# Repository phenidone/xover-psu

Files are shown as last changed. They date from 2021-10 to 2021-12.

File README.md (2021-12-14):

# Preamp Power Supply

This is a PCB design for an analogue preamplifier power supply

## Inputs

Power can be provided as one of:
* high voltage (240V) AC, relay-switched
* high voltage (240V) AC, unswitched,
* low voltage (20+20V) unregulated DC

An opto-isolated input (5-24V DC) is provided to control the power-switching relay.  Low-power (2A) switched AC loads can be
connected via terminals on the PCB, and high power loads (20A) can be switched using spade terminals on the rear of the 
relay.

If the PCB transformer is omitted, unregulated dual-rail DC can be fed into the linear regulator section.  Additional
filter capacitors may also be inserted at this point.  The unmute circuit will NOT work unless the transformer is present or
low-voltage AC is otherwise supplied to the board.

## Outputs

The circuit provides:
* +/- 12-15VDC, linear regulated
* 12VDC from always-on switchmode brick, for control circuits
* un-muting relay output
* 50Hz opto-isolated pulses for external power-sensing logic
* power-relay output

The power-relay terminals can be used as an output port to drive an external
relay, or can be used as an input port to drive the onboard relay if the
remote/relay driver circuit (U2, Q1, etc) is not populated.

The 12VDC output terminal could be used as an input from an external plugpack
if the HLK10M12 is not present.

### Unmute Logic

The UNMUTE output is designed to switch a 12V muting relay and thereby suppress bad noises that occur during power-up/down
brownout of preamplifier and power-amplifier circuits.

The unmute logic uses a slow turn-on RC timer and a fast turn-off RC timer, both of which are charged from opto-isolated pulses
derived from the mains transformer secondary.  The UNMUTE output (12VDC up to 500mA) is enabled after the slow timer charges, 
which is about 1s after power is applied; for a shorter turn-on delay, reduce the value of R2 and/or C1.

When power is withdrawn, the fast timer discharges in about 50ms, which causes Q2 to discharge the C in the slow timer,
thereby immediately shutting off the UNMUTE output and resetting the startup time.

Each RC timer uses a TL431 to provide a distinct transition point, for fast(ish) turn-on/off transitions.

A secondary AC pulse output is provided as bare optoisolator pins, allowing an external logic circuit to safely monitor the presence of AC
power going into the linear regulator.

### Linear Regulation

The dual-rail DC output is designed to power opamp-based preamplifier circuits and as such, has an output of approx 12-15V
DC depending on resistor selection choices.  The circuit should be good for about 250mA, depending on the transformer regulation.

## Construction

The board is very densely populated, and on both sides.  First assemble all the surface-mount components on the board front,
then install all through-hole components (except screw terminals) on the board rear.

### Errata

The pinouts of some TL431 devices have pins 1 and 2 reversed, i.e. they are mis-marked TL432s.  You can, with a little bending
of their leads, install those upside down and it will work.  The layout assumes the pin order is 1=K, 2=R, 3=A.

### Component Sourcing

The major/expensive items required are:
* TE T9GS1L24-12 power relay
* HiLink 10M12 AC/DC switchmode brick
* Vigortronix VTX-120-5412-415 transformer for 15V operation
    * alternative: VTX-120-5412-412 for 12V operation
    * alternative: Block PT-13/2/12 which has a similar footprint
* Bourns PM3700 common-mode choke
* Rectifier filter caps: Panasonic EEEFK 3300u or similar 18mm square electrolytics
* Other silicon and passives - buy it on eBay from China

An 0805 passive sample book is very handy for filling out most of the circuit; low-noise/precision values are not required.

### Output Voltage

Output voltage is selected by voltage dividers on the LM317 and LM337.  
Choose R18 and R28 to be 240R or 270R, then select values for R20 and R23
so that

> R20 = R18 (VOUT / 1.25 - 1)

If R20 is not a convenient value, make a parallel combination e.g. 5k1 and 6k8
in lieu of 3k to get about 15V.

### Regulator Caps

Regulator output capacitors should preferably be tantalum or aluminium electrolytic.
You can use either C6/C14 (SMD) or C7/C15 (through hole) footprints.  Make 
sure the capacitors are rated for notably more than the output voltage, 
e.g. 25V.

Ceramic caps here will cause regulator instability and oscillation.

### Pi Filter

The rectifier filter is a C-R-C pi-filter with 3300u per side.  Choose the resistors (R31, R26 etc) so that
the net voltage drop across them is as much as you can handle, without:
* bringing the unregulated DC rail so low that ripple breaks through the regulators, or
* the resistors overheating (max 100mW each) at your max design-load current

Larger resistors will provide greater ripple smoothing, at the expense of lower voltage
input to the regulators.  Choice will depend on your selection of transformer voltage, 
output voltage, and max expected load current.  A 15V supply has more room here for 
voltage drop (and therefore smoothing) than a 12V supply does.

Bridge them with 0R if you want a simple capacitor-only rectification filter.  Loading all
eight with 10R is probably OK for a 250mA output and will lose you about 0.65V DC and 160mW per rail.

### AC bits

The MOVs and common-mode choke are probably not critical.  Bridge over the 
choke if you're feeling EMI-antisocial, though this may result in HF conducted
EMI reaching your regulated outputs.

Use 500mA M205 slow blow glass fuses; there is one for each of the switchmode and
linear-regulated parts of the supply.  The switched-AC output is not fused, and should be good for 
about 5A before there are issues with terminal blocks.  For switching high-power amplifiers, use the
spade connectors on the rear of the relay.

### Grounding

There are three separate grounds:
* AGND, the centre of the dual-regulated supply
* DGND, ground for the 12V VDD switchmode/logic/control supply
* EARTH, a chassis safety connection

AGND is connected to EARTH via four opposed diodes in a bridge configuration,
which will keep them to no more than about 1.4V apart, but otherwise uncoupled
with respect to noise.

DGND is connected to EARTH via two opposed diodes and a capacitor.  They may
be up to 0.7V apart, and noise from the DC side of the 10M12 should be 
conducted into EARTH via C18.  These ground-lift circuits should be strong 
enough to trip an ELCB if there is a transformer-isolation fault that brings
mains AC power to the low voltage side.

The Vigortronix transformers have exposed steel cores which must be grounded via
mounting screws through the PCB, which are connected via the PCB to the 
EARTH screw terminal.

### PCB

Use a full-thickness (16.mm) PCB; 1mm boards are too flimsy with all of the heavy power supply components mounted.

## TRL and Regulatory

This design is tested and working in a benign environment at Rev.A.  It has not faced MTBF validation,
environmental (thermal+vibration) or EMI compliance testing.

In terms of electrical safety, this design
* is intended for use in Class I (grounded) equipment:
    * a safety-ground connection is mandatory,
    * it must be installed inside an IEC-60950 grounded case per Class I;
* additionally aims to comply with IEC-60950 "reinforced insulation" creepage+clearance rules,
* uses diode-based ground-lift circuits that may not be legal in all jurisdictions for a Class I device,

The design has not been certified by any regulatory body or independent third party testing agency.  You must 
not sell any product containing this power supply without first obtaining certification.

## License

This hardware design is (C) 2021 William Brodie-Tyrrell and is licensed under the CERN OHL; see cern_ohl_v_1_2.pdf

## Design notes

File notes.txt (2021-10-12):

Trace min 10mil for 0.5A

Creepage/clearance per IEC-60950-1
Functional insulation: 3.2/1.5mm
Basic insulation: 3.2/2mm
Reinforced insul: 6.4/4mm

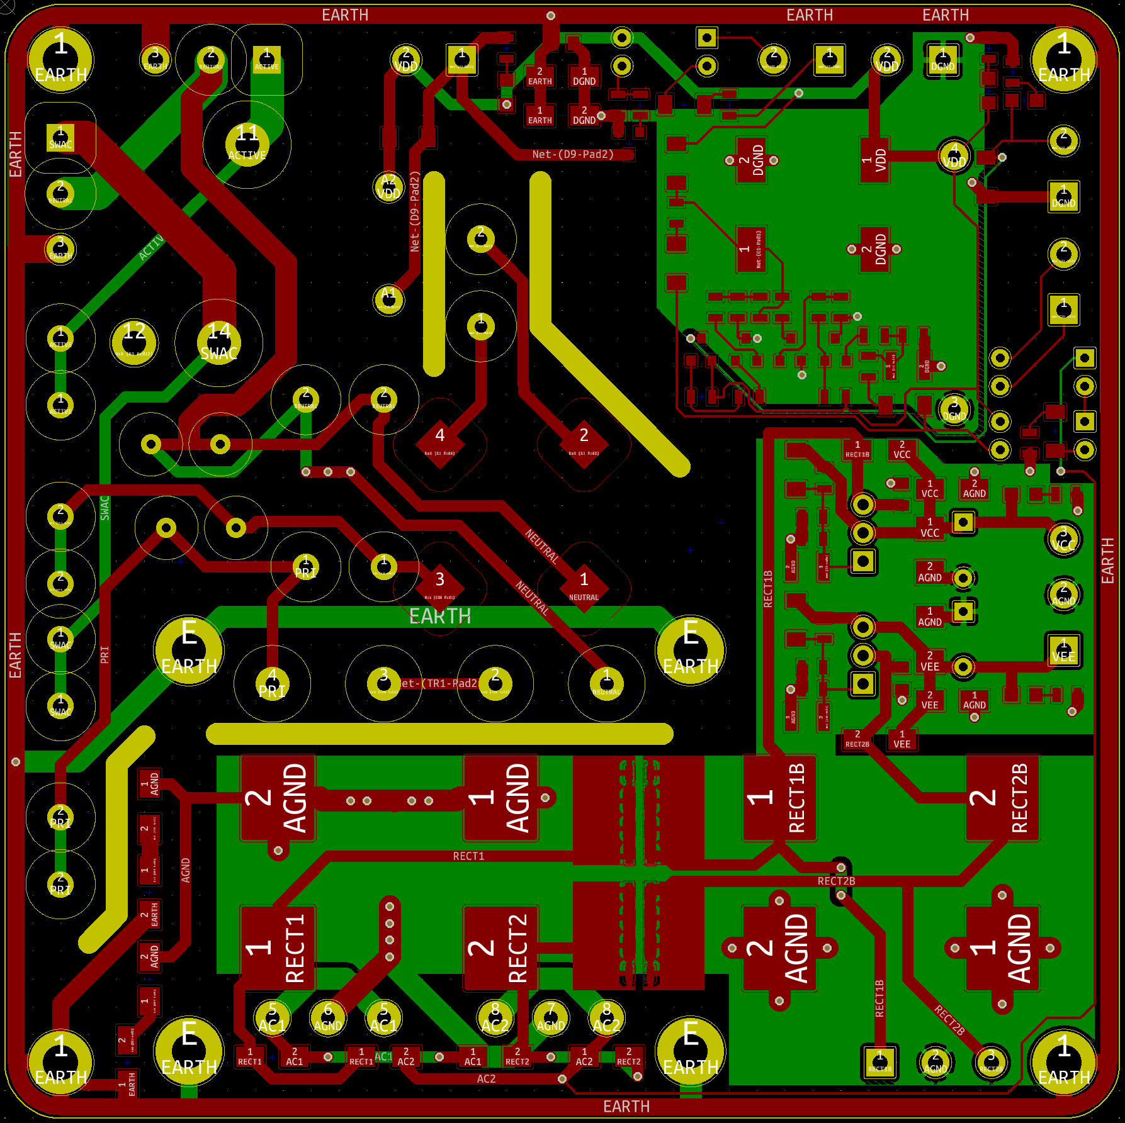
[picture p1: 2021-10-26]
xover-psu-layout.png

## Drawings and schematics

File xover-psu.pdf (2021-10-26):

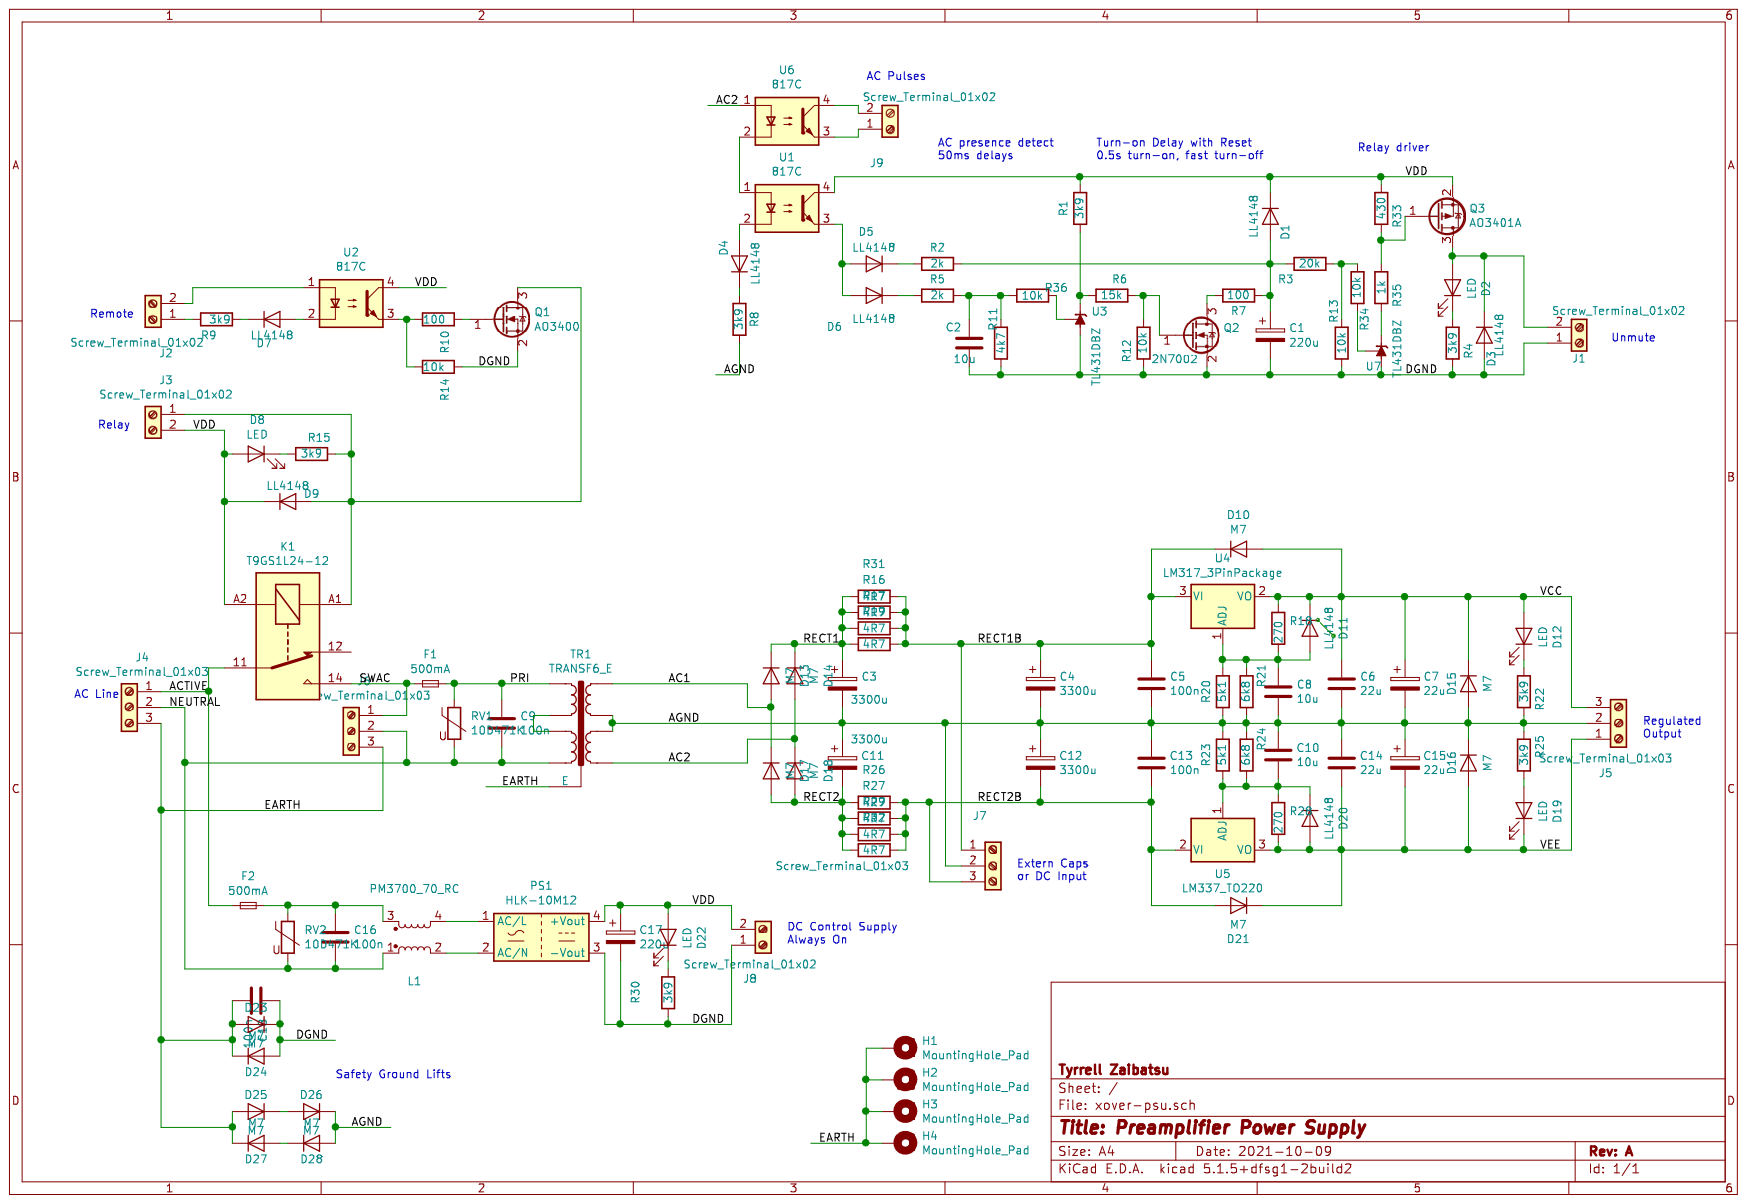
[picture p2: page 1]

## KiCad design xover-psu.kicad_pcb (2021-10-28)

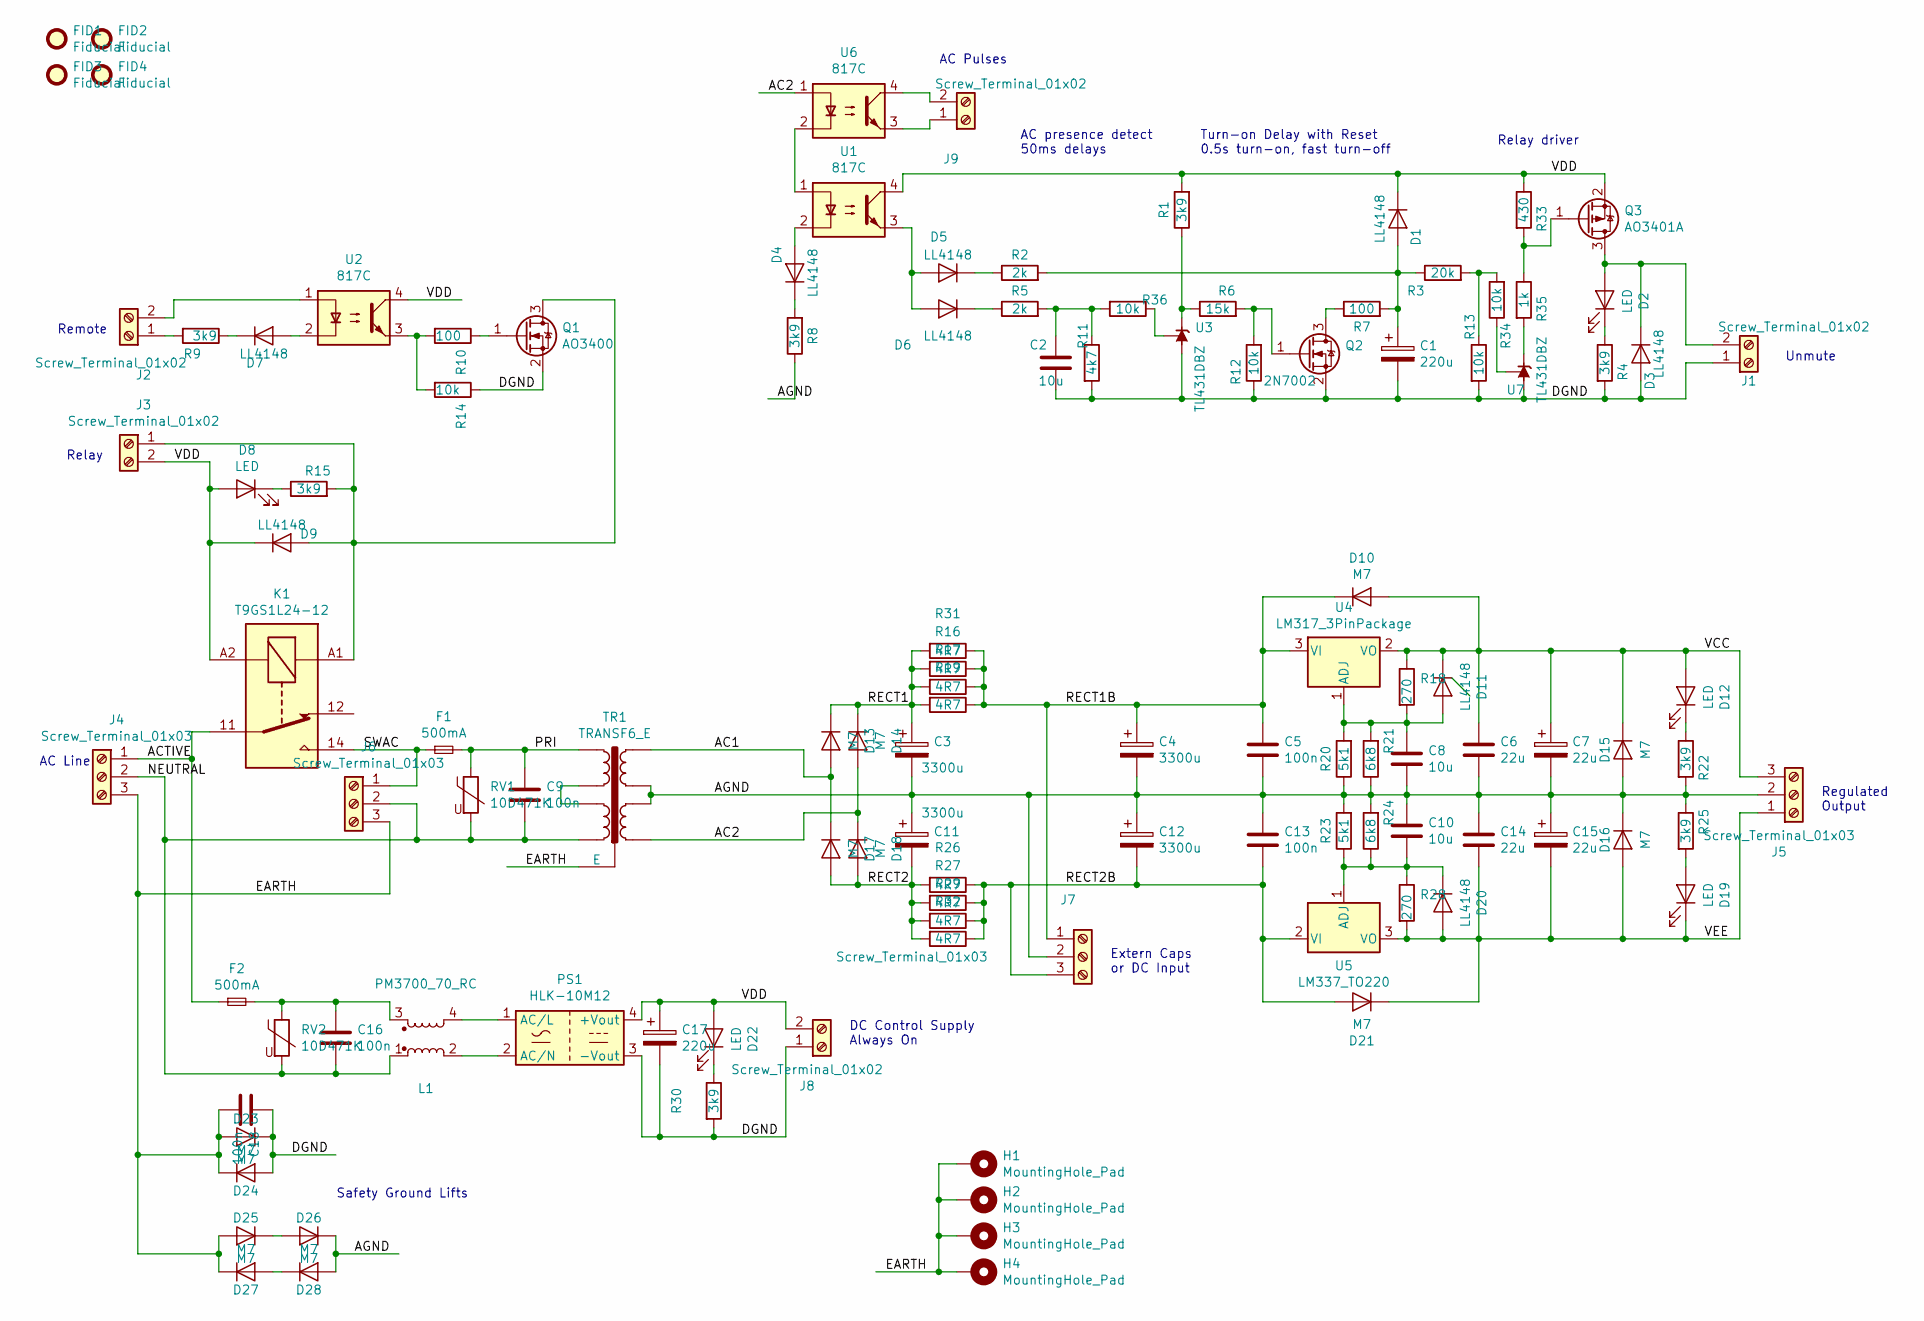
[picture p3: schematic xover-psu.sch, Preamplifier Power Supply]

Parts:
C1, C17: 220u; CP_Elec_10x10; MFG Part Num EEEFP1H221AP
C2, C8, C10: 10u; C_1210
C3, C4, C11, C12: 3300u; CP_Elec_EEEFK-K16
C5, C13, C18: 100n; C_0805
C6, C14: 22u; C_1210_HandSoldering
C7, C15: 22u; CP_Radial_Tantal_D6.0mm_P5.00mm
C9, C16: 100n; C_Rect_L18.0mm_W6.0mm_P15.00mm_FKS3_FKP3; MFG Part Num ECQU2A104KLA
D1, D3, D4, D5, D6, D7, D9, D11, D20: LL4148; D_MiniMELF
D2, D8, D12, D19, D22: LED; LED_0805
D10, D13, D14, D15, D16, D17, D18, D21, D23, D24, D25, D26, D27, D28: M7; D_SMA
F1, F2: 500mA; Fuseholder5x20_6mm
FID1, FID2, FID3, FID4: Fiducial; Fiducial_1mm_Dia_2.54mm_Outer_CopperTop
H1, H2, H3, H4: MountingHole_Pad; MountingHole_3.2mm_M3_DIN965_Pad
J1, J2, J3, J8, J9: Screw_Terminal_01x02; TerminalBlock_Phoenix_MKDS1.5-2pol
J4, J5, J6, J7: Screw_Terminal_01x03; TerminalBlock_Phoenix_MKDS1.5-3pol
K1: T9GS1L24-12; Potter_T9G_Relay
L1: PM3700_70_RC; PM3700
PS1: HLK-10M12
Q1: AO3400; SOT-23
Q2: 2N7002; SOT-23
Q3: AO3401A; SOT-23
R1, R4, R8, R9, R15, R22, R25, R30: 3k9; R_0805
R2, R5: 2k; R_0805
R3: 20k; R_0805
R6: 15k; R_0805
R7, R10: 100; R_0805
R11: 4k7; R_0805
R12, R13, R14, R34, R36: 10k; R_0805
R16, R17, R19, R26, R27, R29, R31, R32: 4R7; R_0805
R18, R28: 270; R_0805
R20, R23: 5k1; R_0805
R21, R24: 6k8; R_0805
R33: 430; R_0805
R35: 1k; R_0805
RV1, RV2: 10D471K; RV_Disc_D12_W3.9_P7.5
TR1: TRANSF6_E; Trafo_CHK-EI54-12VA_Combo_Vigor
U1, U2, U6: 817C; DIP-4_W7.62mm
U3, U7: TL431DBZ; SOT-23
U4: LM317_3PinPackage; TO-220-3_Vertical
U5: LM337_TO220; TO-220-3_Vertical

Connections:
/AC1: D13.2 (A), D17.1 (K), TR1.5
/AC2: D14.2 (A), D18.1 (K), TR1.8, U6.1
/ACTIVE: F2.1, J4.1, K1.11
/AGND: C3.2, C4.2, C5.2, C6.2, C7.2, C8.2, C10.1, C11.1, C12.1, C13.1, C14.1, C15.1, D15.2 (A), D16.1 (K), D26.1 (K), D28.2 (A), J5.2, J7.2, R8.1, R20.1, R21.1, R22.2, R23.2, R24.2, R25.1, TR1.6, TR1.7
/DGND: C1.2, C2.2, C17.2, C18.1, D3.2 (A), D23.1 (K), D24.2 (A), J1.1, J8.1, PS1.3 (-Vout), Q1.2 (S), Q2.2 (S), R4.2, R11.2, R12.1, R13.2, R14.1, R30.2, U3.3 (A), U7.3 (A)
/EARTH: C18.2, D23.2 (A), D24.1 (K), D25.2 (A), D27.1 (K), H1.1, H2.1, H3.1, H4.1, J4.3, J6.3, TR1.E
/NEUTRAL: C9.2, C16.2, J4.2, J6.2, L1.1, RV1.2, RV2.2, TR1.1
/PRI: C9.1, F1.2, RV1.1, TR1.4
/RECT1: C3.1, D13.1 (K), D14.1 (K), R16.2, R17.2, R19.2, R31.2
/RECT1B: C4.1, C5.1, D10.1 (K), J7.1, R16.1, R17.1, R19.1, R31.1, U4.3 (VI)
/RECT2: C11.2, D17.2 (A), D18.2 (A), R26.2, R27.2, R29.2, R32.2
/RECT2B: C12.2, C13.2, D21.2 (A), J7.3, R26.1, R27.1, R29.1, R32.1, U5.2 (VI)
/SWAC: F1.1, J6.1, K1.14
/VCC: C6.1, C7.1, D10.2 (A), D11.1 (K), D12.2 (A), D15.1 (K), J5.3, R18.1, U4.2 (VO)
/VDD: C17.1, D1.1 (K), D8.2 (A), D9.1 (K), D22.2 (A), J3.2, J8.2, K1.A2, PS1.4 (+Vout), Q3.2 (S), R1.2, R33.1, U1.4, U2.4
/VEE: C14.2, C15.2, D16.2 (A), D19.1 (K), D20.2 (A), D21.1 (K), J5.1, R28.2, U5.3 (VO)
unnamed: C1.1, D1.2 (A), R2.2, R3.1, R7.2
unnamed: C2.1, R5.2, R11.1, R36.2
unnamed: C8.1, D11.2 (A), R18.2, R20.2, R21.2, U4.1 (ADJ)
unnamed: C10.2, D20.1 (K), R23.1, R24.1, R28.1, U5.1 (ADJ)
unnamed: C16.1, F2.2, L1.3, RV2.1
unnamed: D2.1 (K), R4.1
unnamed: D2.2 (A), D3.1 (K), J1.2, Q3.3 (D)
unnamed: D4.1 (K), R8.2
unnamed: D4.2 (A), U1.2
unnamed: D5.1 (K), R2.1
unnamed: D5.2 (A), D6.2 (A), U1.3
unnamed: D6.1 (K), R5.1
unnamed: D7.1 (K), R9.1
unnamed: D7.2 (A), U2.2
unnamed: D8.1 (K), R15.1
unnamed: D9.2 (A), J3.1, K1.A1, Q1.3 (D), R15.2
unnamed: D12.1 (K), R22.1
unnamed: D19.2 (A), R25.2
unnamed: D22.1 (K), R30.1
unnamed: D25.1 (K), D26.2 (A)
unnamed: D27.2 (A), D28.1 (K)
unnamed: J2.1, R9.2
unnamed: J2.2, U2.1
unnamed: J9.1, U6.3
unnamed: J9.2, U6.4
unnamed: L1.2, PS1.2 (AC/N)
unnamed: L1.4, PS1.1 (AC/L)
unnamed: Q1.1 (G), R10.1
unnamed: Q2.1 (G), R6.2, R12.2
unnamed: Q2.3 (D), R7.1
unnamed: Q3.1 (G), R33.2, R35.1
unnamed: R1.1, R6.1, U3.1 (K)
unnamed: R10.2, R14.2, U2.3
unnamed: R3.2, R13.1, R34.2
unnamed: R34.1, U7.2 (REF)
unnamed: R35.2, U7.1 (K)
unnamed: R36.1, U3.2 (REF)
unnamed: TR1.2, TR1.3
unnamed: U1.1, U6.2

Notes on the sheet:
Regulated Output
DC Control Supply Always On
Relay
AC Line
Remote
Turn-on Delay with Reset 0.5s turn-on, fast turn-off
Relay driver
AC presence detect 50ms delays
Safety Ground Lifts
Extern Caps or DC Input
Unmute
AC Pulses

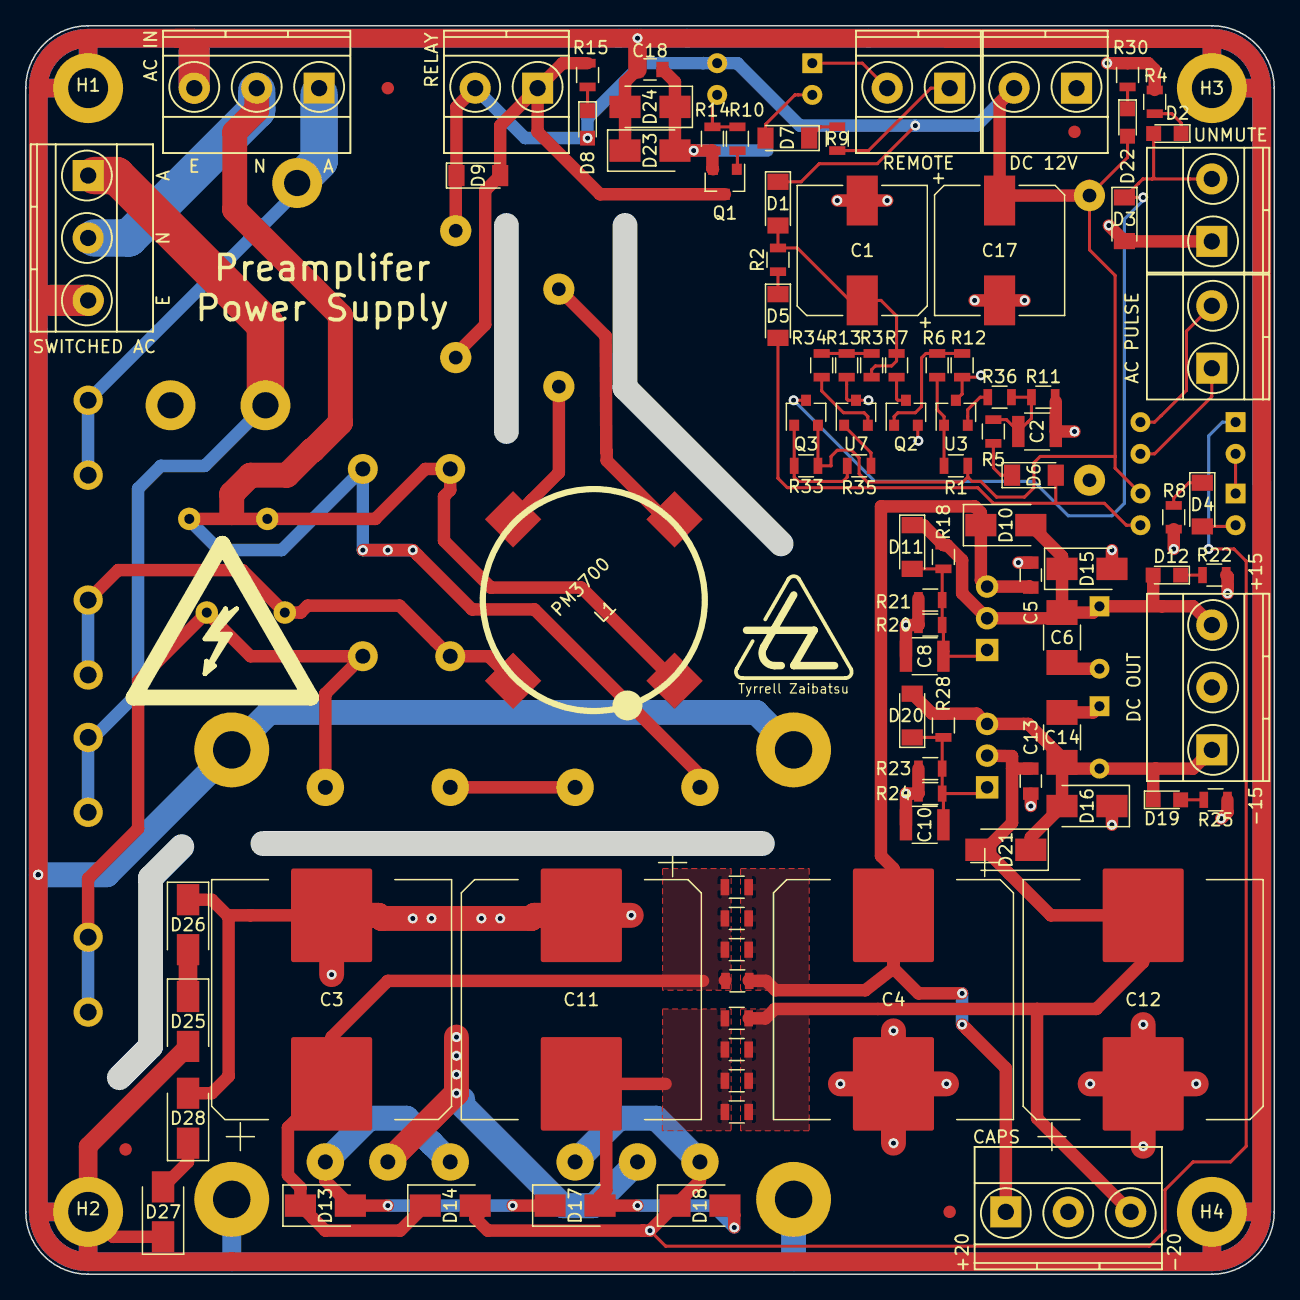
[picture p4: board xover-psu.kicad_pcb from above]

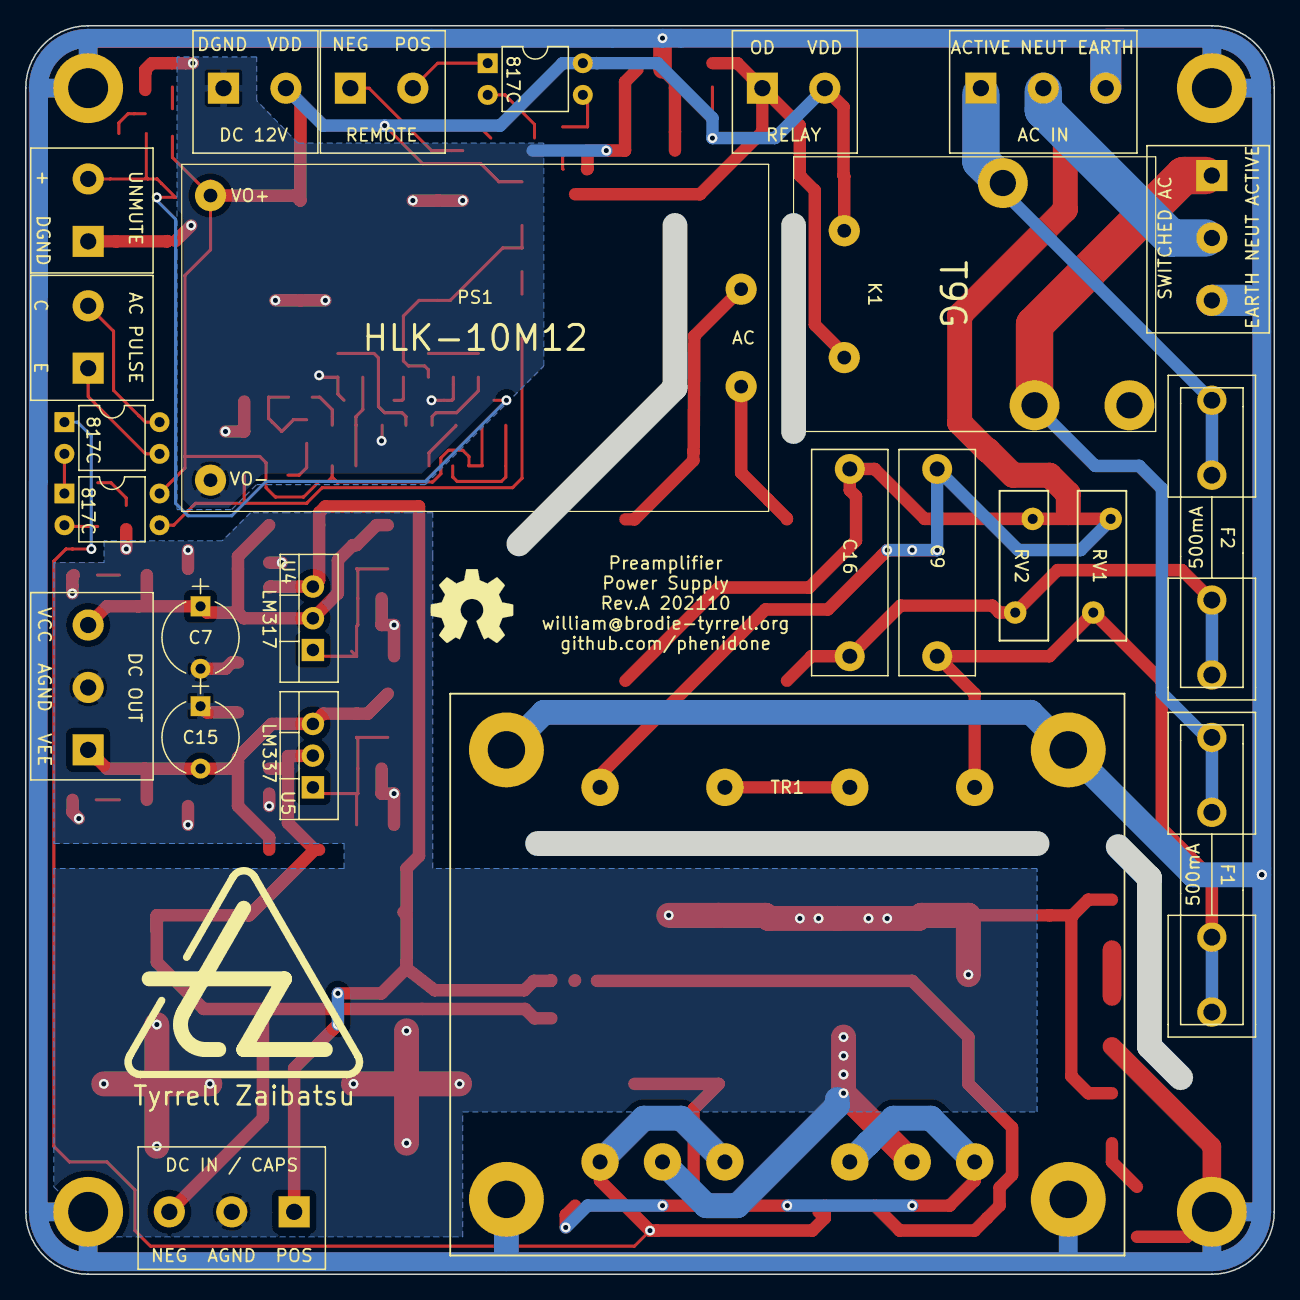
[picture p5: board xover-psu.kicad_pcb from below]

Board: 2 copper layers, 100.0 x 100.0 mm, 117 parts (16 on the bottom side), 55 nets.

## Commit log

2021-10-07 Textbook two-rail linear regulator with LM317 etc.
    [xover-psu.kicad_pcb, xover-psu.sch]
2021-10-09 Added unmute-timing draft schematic (mostly FETs, untested)
    [xover-psu.sch]
2021-10-09 Converted unmute circuit to TL431 for distinct turn-on/off behaviour
    [xover-psu.sch]
2021-10-09 Created PDF schematic
    [xover-psu.sch]
2021-10-10 improved TL431 biasing, higher-ESR filter cap options for stability
    [xover-psu.sch]
2021-10-10 defined all the custom footprints
    [xover-psu.sch]
2021-10-12 Completed placement (no routing) on layout
    [xover-psu.kicad_pcb, xover-psu.sch]
2021-10-14 First pass routing completed for all but the UNMUTE timer/logic
    [xover-psu.kicad_pcb, xover-psu.sch]
2021-10-14 Fixed transformer phase, made some mains tracks fatter
    [xover-psu.kicad_pcb, xover-psu.sch]
2021-10-15 prettified everything - round corners, readable silkscreens, etc.
    [xover-psu-B_Cu.gbr, xover-psu-B_Fab.gbr, xover-psu-B_Mask.gbr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]
2021-10-15 better AGND plane divide, regenerated layout png
    [xover-psu-B_Cu.gbr, xover-psu-B_Fab.gbr, xover-psu-B_Mask.gbr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]
2021-10-25 updated schematic for faster turn-on transition for UNMUTE
    [xover-psu.kicad_pcb, xover-psu.sch]
2021-10-26 tested UNMUTE circuit, improved switch-on/off speed, rejigged mains routing for EMI
    [xover-psu-B_Cu.gbr, xover-psu-B_Fab.gbr, xover-psu-B_Mask.gbr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]
2021-10-28 taped out, updated README
    [xover-psu-B_Fab.gbr, xover-psu.GBL, xover-psu.GBO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]
2021-12-14 updated README to show tested-as-working, plus regulatory details
